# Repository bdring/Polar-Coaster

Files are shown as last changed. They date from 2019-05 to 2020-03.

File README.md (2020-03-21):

## Polar Coaster V2



This is a pen plotter designed to draw things on round drink coasters. It was primarily designed as a simple demostration project of polar kinematics.

I got a lot of requests to post the source files, so here they are. You should have a basic familiarity of how 3D printers or CNC machines work and a basic understanding of how to make gcode. I can only provide basic support via [GitHub issues](<https://github.com/bdring/Polar-Coaster/issues>).

### Source files

- Mechanicals
  - [STL Files](<https://github.com/bdring/Polar-Coaster/tree/master/mechanics/stl>)
  - [3D STEP Assembly File](<https://github.com/bdring/Polar-Coaster/tree/master/mechanics/source>)
- PCB
  - [Schematic](https://github.com/bdring/Polar-Coaster/blob/master/pcb/schematic.pdf)
  - [Gerber Files](<https://github.com/bdring/Polar-Coaster/tree/master/pcb/gerber>)
  - [Source: Diptrace](<https://github.com/bdring/Polar-Coaster/tree/master/pcb/source>)
- BOM ( [work in progress](https://docs.google.com/spreadsheets/d/1ZX7-w3RRlV4LFHbHOMovw8RLWblGm1u_bLe6--jveR4/edit?usp=sharing) )

### Firmware

It uses [Grbl_ESP32 firmware](<https://github.com/bdring/Grbl_Esp32>). Use [polar_coaster.h](https://github.com/bdring/Grbl_Esp32/blob/master/Grbl_Esp32/Machines/polar_coaster.h) as your machine definition file.

### Setup

[Get some coasters from Amazon](https://www.amazon.com/dp/B01H0PO19S)

After you have the frimware loaded use a serial termnial to setup the work coordinate system so the pen 0,0 is roughly near the middle and the pen is up by sending G10 L2 P0 X-43 Y-5. you only need to do this once.

**Centering (important for good quality plots)**

If the machine does not have an accurate center, lines that go near the center will get distorted.

Load a coaster by pressing onto the bed. give a little push down at each of the 6 friction grips. Home the machine by sending $H or clicking the S1 button on the machine. Move the pen carriage to the middle by sending G0 X0 Y0.   Mount a pen so that the tip just touches the coaster. Spin the coaster by hand to draw with the pen. This will give you an indication of how close the pen tip is near the center of the coaster. 

To adjust the center you can use the X axis jogging controls on the WebUI and by loosening and swiveling the arm. Be careful not to accidentally move the pen by hand. 

After you have it close, Click the the X zero button below the jog panel or sending G10 L20 P0 X0.

Verify everything is working by rehoming, sending to X0,Y0 and checking the center.

You need to do this everytime you use a new type of pen or if the plot quality does not look good.

### Usage Instructions

Load a coaster

There are three buttons. The one towrds the front is a homing button. If you click this it will home and the pen carriage will go up. Mount the pen with the tip about 2 mm above the surface.

You can stream gcode or you can put files on a micro SD card. If you name your files 1.nc or 2.nc, you can use the buttons to play those files. Button S2 = 1.nc and S3 = 2.nc.

### Issues.

1. The PCB was designed to allow the use of both 0.9" and 1.0" pitch 19x2 pin ESP32 dev modules. The wider ones tend to have an overhanging antenna section that will interfere with on of the stepper drivers. 
2. Hot Motors: Keep the current very low on the motors. If they get hot, the PLA could get damaged. I like to run TMC2130 drivers in stand alone mode. They are very quient and cool.

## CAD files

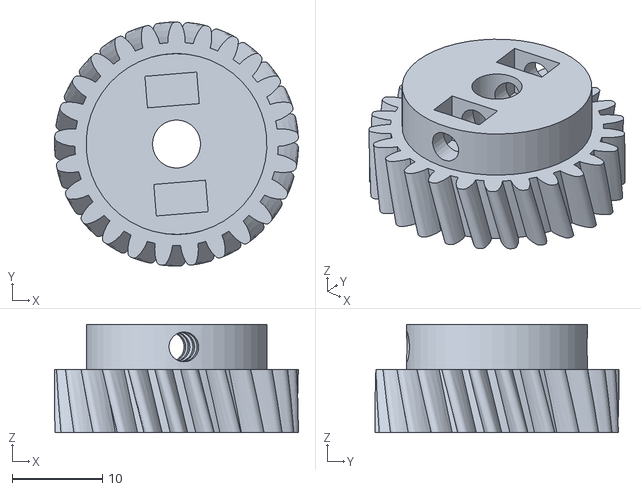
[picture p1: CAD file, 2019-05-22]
mechanics/stl/pc2_drive_gear.stl
27.0 x 27.0 x 12.0

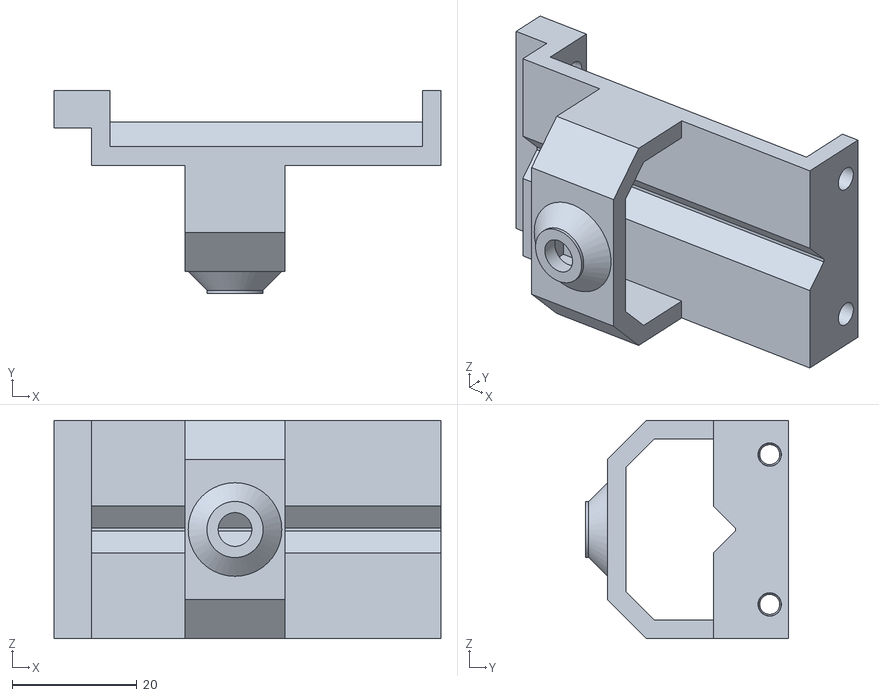
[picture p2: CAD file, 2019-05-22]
mechanics/stl/pc2_pen_carriage.stl
62.0 x 32.5 x 35.0

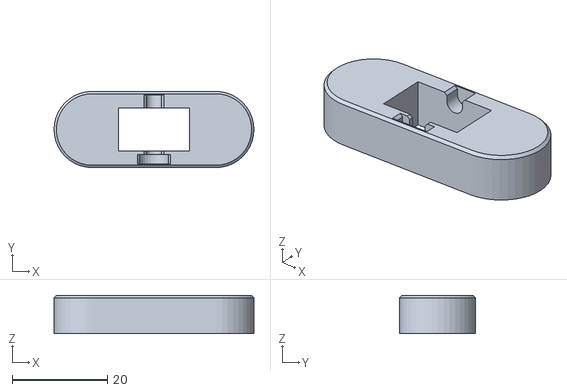
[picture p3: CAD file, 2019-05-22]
mechanics/stl/pc2_rod_cap.stl
42.0 x 16.0 x 8.00

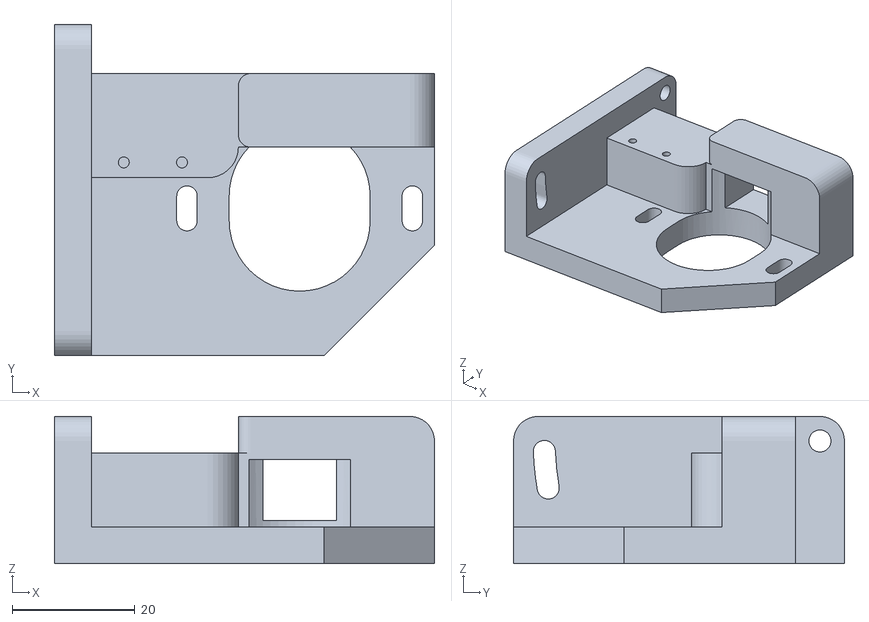
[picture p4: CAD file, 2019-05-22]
mechanics/stl/pc2_arm_block.stl
62.0 x 54.0 x 24.0

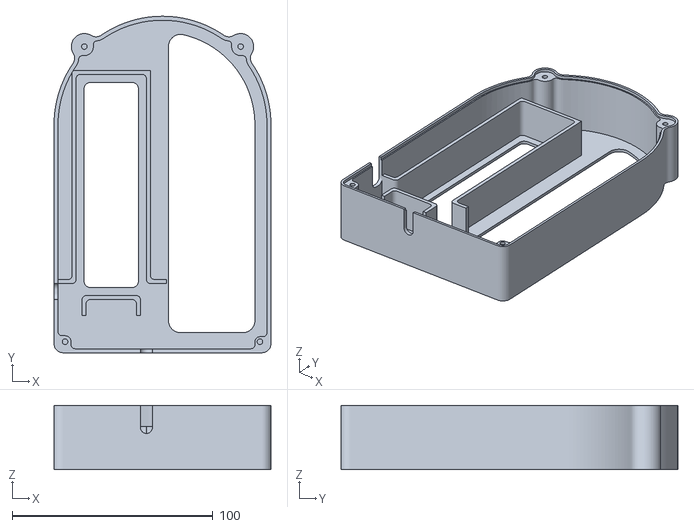
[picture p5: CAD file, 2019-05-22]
mechanics/stl/pc2_base.stl
108.0 x 167.5 x 32.0

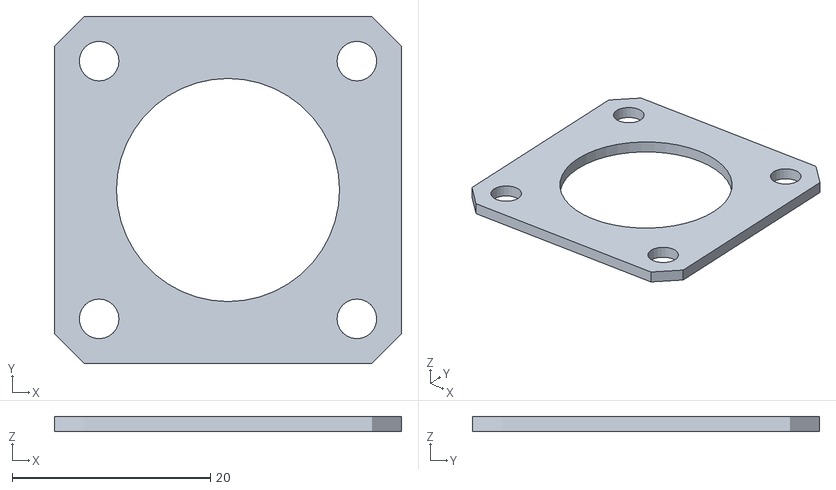
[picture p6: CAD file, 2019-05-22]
mechanics/stl/nema14_spacer.stl
35.0 x 35.0 x 1.50

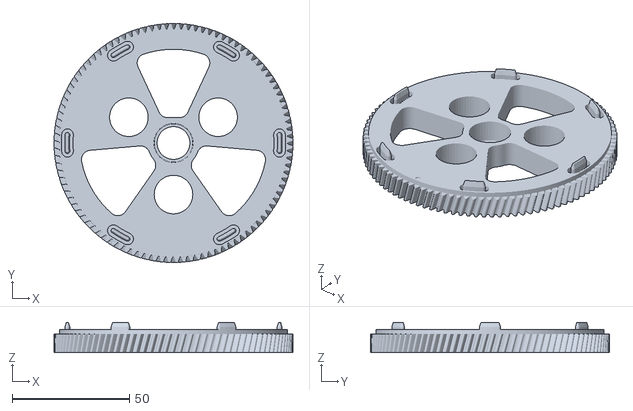
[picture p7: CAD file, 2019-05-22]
mechanics/stl/pc2_gear_bed.stl
102.0 x 102.0 x 13.0

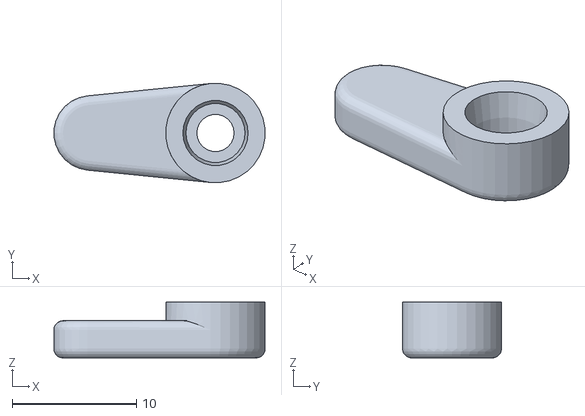
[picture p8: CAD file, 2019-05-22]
mechanics/stl/pc2_pen_cam.stl
17.0 x 7.96 x 4.50

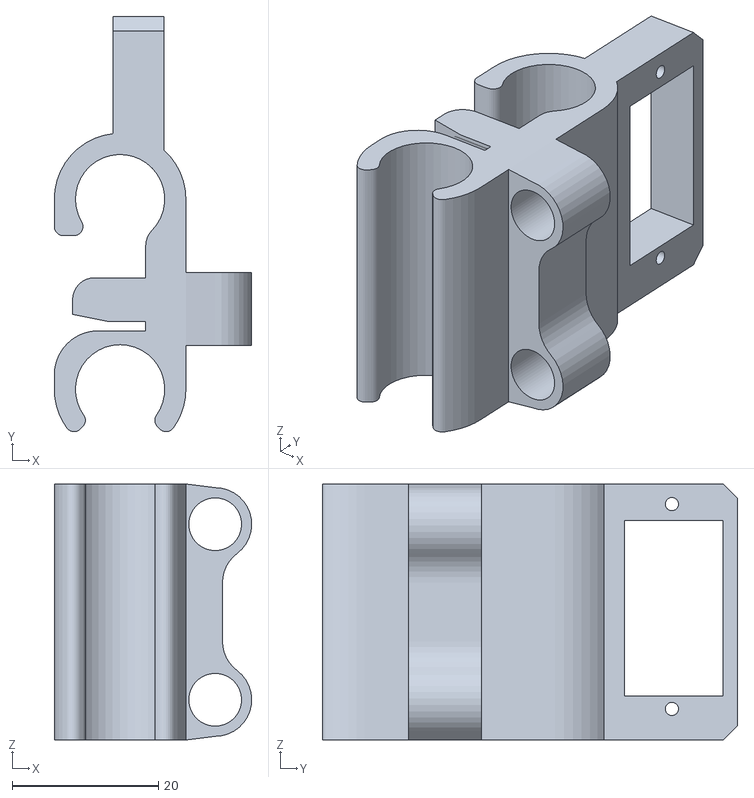
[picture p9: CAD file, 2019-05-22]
mechanics/stl/pc2_carriage.stl
27.0 x 56.8 x 35.0

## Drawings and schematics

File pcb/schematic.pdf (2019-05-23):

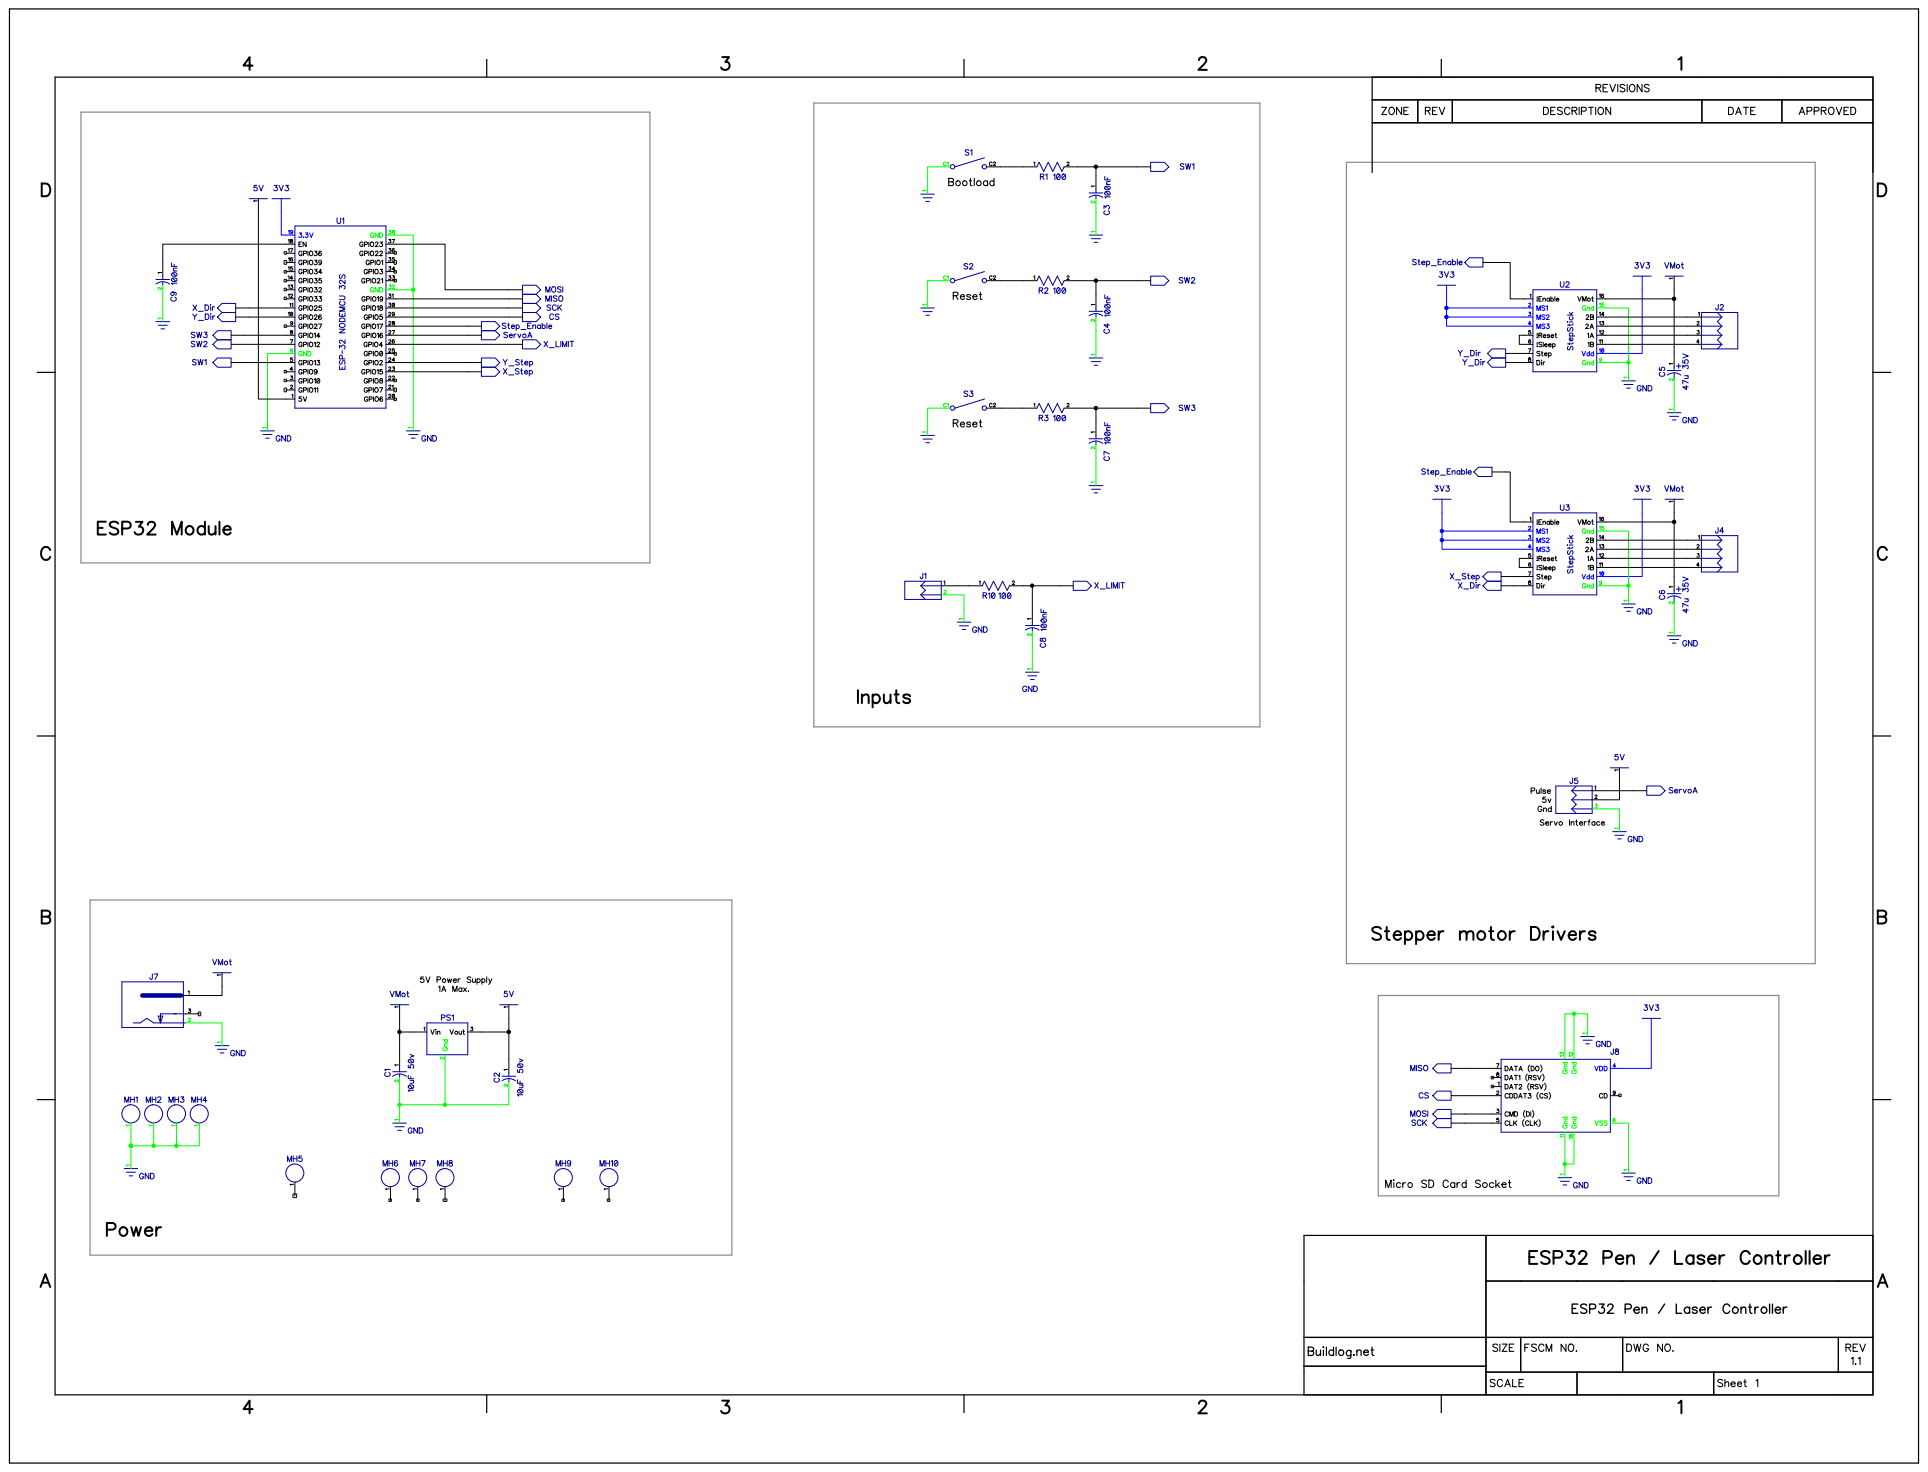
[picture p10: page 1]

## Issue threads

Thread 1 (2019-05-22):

Alternative Design Ideas

bdring, 2019-05-22:
It has been noted that other countries use different coaster sizes. There is a not a lot of flexibility in the current design, especially going to a larger diameter coaster.

The firmware can handle any size and probably accommodate other changes. If you are looking at a redesign, here are some thoughts.

1. The board does not need to be part of the design. A simpler existing board could be used remotely or packaged within the base. I sell some on [Tindie](https://www.tindie.com/products/33366583/pen-plotter-controller-kit-for-esp32-tmc2130/).

2. The geared rotational bed is complex to model. Someone suggested a direct drive. That is probably doable without affecting quality. I would probably suggest a [metal hub](https://www.servocity.com/770-set-screw-hubs), rather that direct mounting of the 3D printed part. It is more likely to be concentric and could buffer the heat from the motor.

fastriker, 2019-05-22:
I actually thought about a parameterized OpenSCAD model. Maybe also the gears can keep their size and an extra plate on top for the coaster lead to a constant gear transmission ratio. Then the board can also work for machines with different diameter.

bdring, 2019-05-22:
@fastriker You would need to increase the travel of the linear axis too. Maybe just move it out and increase the rod length.

dereulenspiegel, 2019-05-27:
I am actually currently trying to solve this. I increased the height of the "big gear" and added inserts for magnets. Further I modeled a platform which can hold 107mm coasters (pretty standard in Germany) which also has inserts for 3 magnets. This would allow for swappable platforms. The height of the "arm tower" is also increased by 10mm, but I probably need to increase it more.
I am currently waiting for the PCBs and other parts to try a real world assembly. If this works as expected I will publish the changes.

fastriker, 2019-05-29:
> @fastriker You would need to increase the travel of the linear axis too. Maybe just move it out and increase the rod length.

You are right - I didn't thought about that. But maybe it is also not always necessary to use the full space of the coaster.

> I am actually currently trying to solve this. I increased the height of the "big gear" and added inserts for magnets. Further I modeled a platform which can hold 107mm coasters (pretty standard in Germany) which also has inserts for 3 magnets. This would allow for swappable platforms. The height of the "arm tower" is also increased by 10mm, but I probably need to increase it more.

That is also a nice quick solution - and also interesting for me.

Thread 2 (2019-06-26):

BOM corrections

povi2946, 2019-06-26:
Hi,
I understand that BOM is in progress and not everything is listed.
But I noticed that one listing is misleading.
In schematic and a digikey link C5,C6 capacitors are 47uF, but in the BOM it says it's 4.7uF.
https://docs.google.com/spreadsheets/d/1ZX7-w3RRlV4LFHbHOMovw8RLWblGm1u_bLe6--jveR4/edit#gid=0&range=B34
Hopefully it's 47uF, as I already purchased some.

Thanks
P.S. Once I finished building I would share a complete BOM for the update.

bdring, 2019-06-26:
@povi2946

Thanks, you are correct. I updated the BOM.

Closed 2019-06-26.

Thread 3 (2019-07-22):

How to fasten the small gear?

dereulenspiegel, 2019-07-22:
Not really an issue, more of a question. What screw do I need to fasten the small gear? I tried with an M8x8mm screw. While that keeps the gear in place, the screw head interfers with the big gear.
Thanks in advance :)

bdring, 2019-07-22:
I think I used an m3 square nut with a 6mm set screw in that gear.

dereulenspiegel, 2019-07-22:
Thanks, I will try that.

Closed 2019-07-22.

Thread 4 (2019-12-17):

BOM link for motor isn't working.

osbock, 2019-12-17:
I found a couple other Nema14x20mm steppers on that site, but don't know which one.

- 1.8 degree: https://www.omc-stepperonline.com/nema-14-stepper-motor/nema-14-bipolar-1-8deg-5ncm-7-08oz-in-0-4a-10v-35x35x20mm-4-wires.html

- 0.9 degree: https://www.omc-stepperonline.com/nema-14-stepper-motor/nema-14-bipolar-0-9deg-5ncm-7-08oz-in-0-5a-5v-35x35x20mm-4-wires.html

osbock, 2019-12-17:
Actually I looked at the original URL and it's probably this one:
https://www.omc-stepperonline.com/nema-14-stepper-motor/nema-14-bipolar-1-8deg-5ncm-7-08oz-in-0-4a-10v-35x35x20mm-4-wires.html

bdring, 2019-12-17:
That one should work. 0.9deg would work too if you double the steps/mm settings

osbock, 2019-12-18:
Two more BOM questions.
1. What is the 3mm shaft for? I can't find precut 65mm shafts, so wondering how critical end finish is.
2. I assume the belt is cut 6mm gt2 like the first version? it's not listed in the BOM

bdring, 2019-12-18:
3mm shafts are for the Pen up/down. They should be high polish finish.

Yes, cut GT2 belt

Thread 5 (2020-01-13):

Grbl Link is broken

loganYdid, 2020-01-13:
It appears that he link to the polar coaster branch of Grbl_ESP32 provided in the readme is broken

bdring, 2020-01-13:
Thanks for pointing that out.

Fixed the readme. The Polar Coaster features are now in the master branch.

Closed 2020-01-13.

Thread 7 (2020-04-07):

Can u take a picture from the side of the limit switch?

vascobarbosa, 2020-04-07:
On the boom theres this link for it :

https://www.amazon.com/WGCD-125V-Micro-Limit-Switch/dp/B06XFL4MZ2/ref=sr_1_21

but on the board there's only 2 holes.

Got it sorry sorry

Closed 2020-04-07.

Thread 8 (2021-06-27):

Not enough memory

Project3334, 2021-06-27:
When we try to download the firmware into the ESP32 controller we get the following error:

error for compiling board NodeMCU-32S
Text section exceeds available space in board
Sketch too big; see https://support.arduino.......
Error compiling for board NodeMCU32-S.

Hopefully you can help us with this problem.

Closed 2021-06-30.

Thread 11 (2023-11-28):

antenna  interfere with the stepper motor driver

897180673, 2023-11-28:
Most of the time, only one of the two stepper motors can rotate. In readme README.md, it is described that the antenna will interfere with the stepper motor driver. so,How to avoid it.  thanks for you reply

897180673, 2023-12-14:
done ! Insufficient power supply

Closed 2023-12-14.

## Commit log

2019-05-22 Added sample gcode
2019-05-23 Adding PDF of schematic
2019-05-23 Add Schematic link to README.md
